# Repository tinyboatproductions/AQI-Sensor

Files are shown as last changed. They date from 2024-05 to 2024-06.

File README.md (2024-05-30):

# AQI-Sensor
Basic data logging AQI sensor
A basic sensor to log AQI/Dust in the air.

## Goal
The goal of this project was to create a dust sensor/AQI sensor that will be able to track the air quailty over time. 
I wanted to be able to capture the time of each measurment and take readings for a long time, to enable me to test air filters/just keep track.
I designed this around the Grove Dust Sensor from [SEEED Studio](https://www.seeedstudio.com/Grove-Dust-Sensor-PPD42NS.html). The sensor claims to measure dust over 1um.
The brain is an ESP32 which will be able to grab the time from the internet and report that into the reading. 
Two other envrionmental sensors are used to collect temperature and humidity (AHT20) and to collect gas concentrations (ENS160).
The data will all be logged in a text file on an SD card attached to the module. This file can then be converted to a CSV file for processing.
The OLED screen will allow for quick referance of the current reading as well as the average reading over the whole measurment time. 

## To Do
- [X] Remove extra code
- [X] Clean up the OLED output
- [ ] ~~Data processing code~~
- [X] Wiring diagram
- [X] Make a case
- [ ] Arange the code so the screen is setup first and outputs any errors

## Parts
- [ESP32](https://www.amazon.com/gp/product/B08246MCL5/ref=ppx_yo_dt_b_search_asin_title?ie=UTF8&th=1)
- [Grove Dust sensor](https://www.seeedstudio.com/Grove-Dust-Sensor-PPD42NS.html)
- [SD Card Module for Arduino](https://www.amazon.com/gp/product/B07BJ2P6X6/ref=ppx_yo_dt_b_search_asin_title?ie=UTF8&psc=1)
- [64x128 OLED](https://www.amazon.com/gp/product/B085WCRS7C/ref=ppx_yo_dt_b_search_asin_title?ie=UTF8&psc=1)
- [ENS160 from Sparkfun](https://www.sparkfun.com/products/20844)
- [AHT20 from Adafruit](https://www.adafruit.com/product/4566)

## Links To More Info
- Video: https://youtu.be/t2bbnQ1g2lM
- Instructable: https://www.instructables.com/Air-Quality-Monitor-2/
- Printables: https://www.printables.com/model/895121-air-quailty-monitor-case

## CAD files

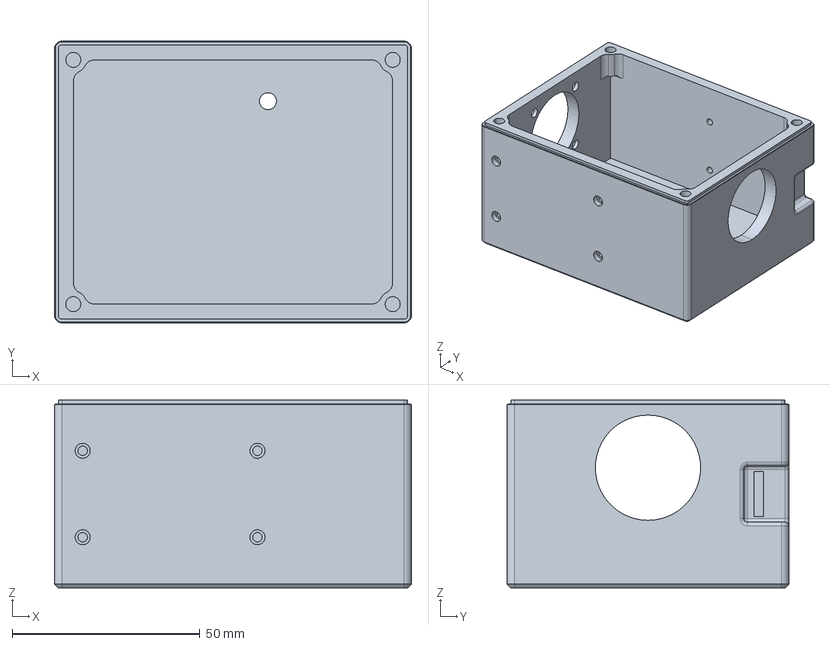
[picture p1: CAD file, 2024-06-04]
Models/CaseBase_V0.5.STEP
95.0 x 75.0 x 50.0 mm

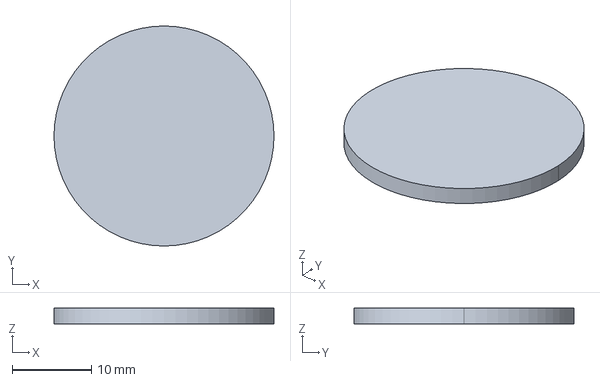
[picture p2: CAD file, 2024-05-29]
Models/Grate.STEP
27.8 x 27.8 x 2.00 mm

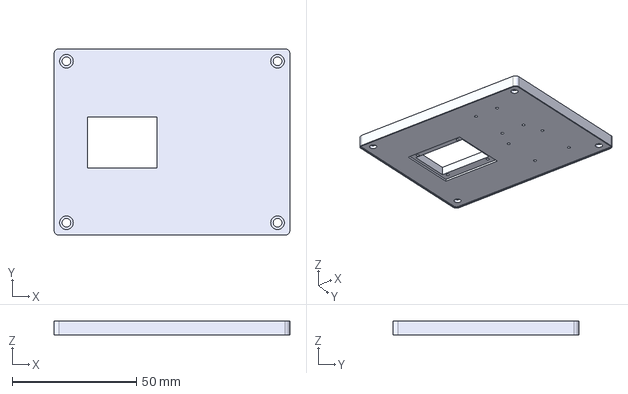
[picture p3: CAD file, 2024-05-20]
Models/CaseLid_v0.2.STEP
95.0 x 75.0 x 5.50 mm

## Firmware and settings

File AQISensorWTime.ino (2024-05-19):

/*
ESP Write to File
3/12/24
Referances
NTP time : https://lastminuteengineers.com/esp32-ntp-server-date-time-tutorial/
File Com: https://www.instructables.com/Light-Color-Tracker/
OLED: https://randomnerdtutorials.com/esp32-ssd1306-oled-display-arduino-ide/

*/

//Stuff needed for the SD card
#include "SPI.h"
#include "SD.h"
#include "FS.h"
#include "Wire.h"

//Stuff needed for the NTP sever (getting the time from the internet)
#include "WiFi.h"
#include "time.h"

//Stuff for the screen
#include <Adafruit_GFX.h>
#include <Adafruit_SSD1306.h>
#define SCREEN_WIDTH 128 // OLED display width, in pixels
#define SCREEN_HEIGHT 64 // OLED display height, in pixels
#define OLED_RESET    -1

//Password and stuff
#include "arduino_secrets.h"

//SparkFun AQI Sensor
#include "SparkFun_ENS160.h"

//adafruit AHT20
#include <Adafruit_AHTX0.h>
Adafruit_AHTX0 aht;
float temperature = 0;
float humidityA = 0;

//Stuff needed to get the time
const char* ssid = SECRET_SSID;
const char* password = SECRET_PSWD;

const char* ntpServer = "pool.ntp.org";
const long gmtOffset_sec = -21600;
const int daylightOffset_sec = 3600;

//global variables beacuase I cannot be assed to pass these back and forth without screwing it up
String fileName = "";
String timeString = "";
File myFile;
const int CS = 5;


//declare the display
Adafruit_SSD1306 display(SCREEN_WIDTH, SCREEN_HEIGHT, &Wire, OLED_RESET);

//Stuff to make the AQI sensor work, all good practices are out the window, i just know how to write basic stuff dont @ me
int AQIpin = 34;
unsigned long duration;
unsigned long starttime;
unsigned long sampletime_ms = 30000;//sampe 30s ;
unsigned long lowpulseoccupancy = 0;
float ratio = 0;
float concentration = 0;

float runningTotal = 0;
int numMeasurments = 1;
int goodValues = 0;
float avg = 0;

//ENS stuff
SparkFun_ENS160 myENS; 
int ensStatus;
int ppb = 0;
int ppm = 0;
int aqi = 0;
int flags = 0;

void setup() {
  // put your setup code here, to run once:
  Wire.begin();
  Serial.begin(115200); //Create a serial output for debugging
  Serial.println();
  Serial.println("Begin");
  wifiConnection();
  setupSD(); // MUST BE FORMATED FAT NOT FAT32
  pinMode(AQIpin, INPUT); // setup the AQI sensor pin
  aht.begin();
  ensSetup();
  displaySetup();
}

void loop() {
  duration = pulseIn(AQIpin, LOW);
  lowpulseoccupancy = lowpulseoccupancy+duration;

  if ((millis()-starttime) > sampletime_ms)//if the sampel time == 30s
  {
    ratio = lowpulseoccupancy/(sampletime_ms*10.0);  // Integer percentage 0=>100
    concentration = 1.1*pow(ratio,3)-3.8*pow(ratio,2)+520*ratio+0.62; // using spec sheet curve
    numMeasurments += 1;

    if(concentration > 1){
      goodValues += 1;
      runningTotal += concentration;
      avg = runningTotal / goodValues;
    } else {
      concentration = 0.0;
    }
    lowpulseoccupancy = 0;
    starttime = millis();
    Serial.print("Concentration: ");
    Serial.println(concentration);  // this seems block for 30 seconds so no delay is needed
    printLocalTime(); //update the time to be current
    appendFile(SD, fileName.c_str(), timeString.c_str()); //Add the time to the file as a string
    appendFile(SD, fileName.c_str(), ",");
    String TempCON = String(concentration); //Convert the reading from a float to a string
    appendFile(SD, fileName.c_str(), TempCON.c_str());
    appendFile(SD, fileName.c_str(), ",");

    //Print AQI Stuff
    Serial.print("Air Quality Index (1-5) : ");
    aqi = myENS.getAQI();
		Serial.println(aqi);
    String TempAQI = String(aqi); //Convert the reading from a float to a string
    appendFile(SD, fileName.c_str(), TempAQI.c_str()); //Add the aqi to the file as a string
    appendFile(SD, fileName.c_str(), ",");

		Serial.print("Total Volatile Organic Compounds: ");
    ppb = myENS.getTVOC();
		Serial.print(ppb);
		Serial.println("ppb");
    String TempPPB = String(ppb); //Convert the reading from a float to a string
    appendFile(SD, fileName.c_str(), TempPPB.c_str()); //Add the TVOC to the file as a string
    appendFile(SD, fileName.c_str(), ",");


		Serial.print("CO2 concentration: ");
    ppm = myENS.getECO2();
		Serial.print(ppm);
		Serial.println("ppm");
    String TempPPM = String(ppm); //Convert the reading from a float to a string
    appendFile(SD, fileName.c_str(), TempPPM.c_str()); //Add the CO2 to the file as a string
    appendFile(SD, fileName.c_str(), ",");

	  Serial.print("Gas Sensor Status Flag (0 - Standard, 1 - Warm up, 2 - Initial Start Up): ");
    flags = myENS.getFlags();
    Serial.println(flags);

    sensors_event_t humidity, temp;
    aht.getEvent(&humidity, &temp);
    Serial.print("Temperature: "); Serial.print(temp.temperature); Serial.println(" degrees C");
    Serial.print("Humidity: "); Serial.print(humidity.relative_humidity); Serial.println("% rH");
    String TempTemp = String(temp.temperature); //Convert the reading from a float to a string
    appendFile(SD, fileName.c_str(), TempTemp.c_str()); //Add the CO2 to the file as a string
    appendFile(SD, fileName.c_str(), ",");
    String TempRH = String(humidity.relative_humidity); //Convert the reading from a float to a string
    appendFile(SD, fileName.c_str(), TempRH.c_str()); //Add the CO2 to the file as a string
    appendFile(SD, fileName.c_str(), ",");

    appendFile(SD, fileName.c_str(), "\n");

    displayUpdate();  //Update the OLED display
		Serial.println();
  }

}

//Connect to the wifi and get the time, pass back to the setup function
void wifiConnection(){
  //connect to WiFi
  Serial.printf("Connecting to %s ", ssid);
  WiFi.begin(ssid, password);
  while (WiFi.status() != WL_CONNECTED) {
      delay(500);
      Serial.print(".");
  }
  Serial.println(" CONNECTED");

  //init and get the time
  configTime(gmtOffset_sec, daylightOffset_sec, ntpServer);
  printLocalTime();

  //disconnect WiFi as it's no longer needed
  WiFi.disconnect(true);
  WiFi.mode(WIFI_OFF);
}

//Setup writing to the SD card, create the file name and add a header to the file
void setupSD(){
  Serial.print("Initializing SD card...");
  if (!SD.begin(CS)) {
    Serial.println("initialization failed!");
    while (1);
  }
  Serial.println("initialization done.");

  //Create the file name with the current time
  fileName = "/" + String(timeString) + ".txt";
  Serial.print("File Name: ");
  Serial.println(fileName);
  myFile = SD.open("fileName.txt", FILE_WRITE);
  myFile.close();

  //Make sure the card is there
  uint8_t cardType = SD.cardType();
  if(cardType == CARD_NONE){
    Serial.println("no Card");
  }

  appendFile(SD, fileName.c_str(), "Time, Concentration, AQI, TVOC, CO2, *C, %RH\n");

}

//setup the display and print out a ready message
void displaySetup(){
  display.begin(SSD1306_SWITCHCAPVCC, 0x3C);
  display.clearDisplay();
  display.setTextSize(2);
  display.setTextColor(WHITE);
  display.clearDisplay();
  display.setCursor(0,0);
  display.println("Ready!");
  display.display();
  Serial.println("Screen setup done.");
}

void ensSetup(){
  if( !myENS.begin() )
	{
		Serial.println("Could not communicate with the ENS160, check wiring.");
		while(1);
	}
  if( myENS.setOperatingMode(SFE_ENS160_RESET) )
  Serial.println("Ready.");
	delay(100);
	myENS.setOperatingMode(SFE_ENS160_STANDARD);
  ensStatus = myENS.getFlags();
	Serial.print("Gas Sensor Status Flag (0 - Standard, 1 - Warm up, 2 - Initial Start Up): ");
	Serial.println(ensStatus);

  sensors_event_t humidity, temp;
  aht.getEvent(&humidity, &temp);
  temperature = temp.temperature;
  humidityA = humidity.relative_humidity;
  // Give values to Air Quality Sensor. 
  myENS.setTempCompensationCelsius(temperature); 
  myENS.setRHCompensationFloat(humidityA); 
}

//get the current time and put it onto the global time string
void printLocalTime(){
  struct tm timeinfo;
  if(!getLocalTime(&timeinfo)){
    Serial.println("Failed to obtain time");
    return;
  }
  Serial.println(&timeinfo, "%A %B %d %Y %H.%M.%S");
  char time[32];
  strftime(time,32, "%B%d%Y%H.%M.%S", &timeinfo);
  timeString = time;
  //Serial.println(time);
  return;
}

//update the OLED display
void displayUpdate(){
  display.setTextSize(2);
  display.setTextColor(WHITE);
  display.clearDisplay();
  display.setCursor(0,0);
  display.print("2.5:");
  display.println(concentration);
  display.print("Avg:");
  display.println(avg);
  display.print("VOC:");
  display.println(ppb);
  display.print("CO2:");
  display.println(ppm);

  display.display();
}

void appendFile(fs::FS &fs, const char * path, const char * message){
  Serial.printf("Appending to file: %s\n", path);

  File file = fs.open(path, FILE_APPEND);
  if(!file){
    Serial.println("Failed to open file for appending");
    return;
  }
  if(file.print(message)){
      Serial.println("Message appended");
  } else {
    Serial.println("Append failed");
  }
  file.close();
}

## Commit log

2024-05-20 Uploaded case files
    [CaseBase_V0.2.STEP, CaseLid_v0.2.STEP]
2024-05-29 Upload new case files
    Upload STEP files for the CaseBase_V0.3 and Grate
    [CaseBase_V0.3.STEP, Grate.STEP]
2024-06-04 Add files via upload
    Fixed an error with the location of the dust sensor
    [CaseBase_V0.5.STEP]
